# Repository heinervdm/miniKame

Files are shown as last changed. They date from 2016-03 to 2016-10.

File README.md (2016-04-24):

# Kame (MiniKame)

<p align="center">
 
</p>

[¿What do I need for building this robot?](https://github.com/bqlabs/miniKame/wiki/BOM)

[¿Where can I find the assembly model?](https://github.com/bqlabs/miniKame/blob/develop/parts/freecad/miniKame.fcstd)

# License

Son of [Kame](https://github.com/bqlabs/kame)

<p align="center">

</p>

# Remixes
[PoorKame](https://github.com/owenlab/PoorKame) by [owenlab](https://github.com/owenlab)

[FatKame](https://github.com/Blomdoft/fatKame) by [Blomdoft](https://github.com/Blomdoft)

# Other



Sponsored by BQ till march 2016

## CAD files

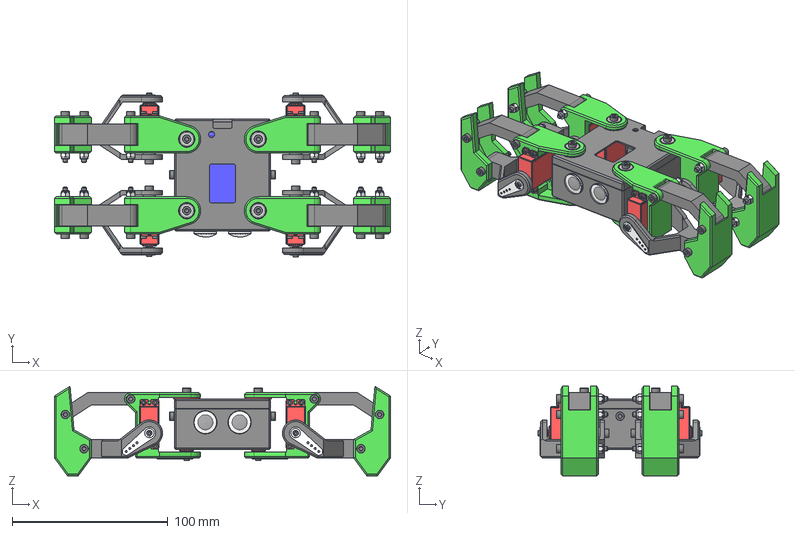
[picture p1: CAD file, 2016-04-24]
parts/freecad/miniKame.fcstd
216.0 x 105.3 x 57.6 mm
Clone of TGY-306G003
Clone of TGY-306G
Clone of TGY-306G004
Clone of TGY-306G005
Clone of TGY-306G006
Clone of TGY-306G007
Clone of TGY-306G008
Clone of TGY-306G009
Clone of horn001 (Mirror #9)
Clone of horn002 (Mirror #10)
Clone of horn001 (Mirror #11)
Clone of horn002 (Mirror #12)
Clone of legA (Mirror #17)
Clone of foot (Mirror #18)
Clone of bracket (Mirror #20)
Clone of legA (Mirror #21)
Clone of foot (Mirror #22)
Clone of bracket (Mirror #24)
Clone of legB (Mirror #30)
Clone of legB (Mirror #31)
Clone of spacer (Mirror #39)
Clone of spacer (Mirror #40)
Clone of bodyB
Clone of bodyA
eye-base
black-eye
eye-cover
eye-base001
eye-cover001
black-eye001
Clone of bearing
Clone of bearing002
Clone of bearing003
Clone of bearing004
Clone of bearing001
Clone of bearing005
Clone of bearing006
Clone of bearing007
Clone of hex-m3-8mm
Clone of hex-m3-8mm001
Clone of hex-m3-8mm002
Clone of hex-m3-8mm003
Clone of hex-m3-8mm004
Clone of hex-m3-8mm005
Clone of hex-m3-8mm006
Clone of hex-m3-8mm007
Clone of hex-m3-8mm008
Clone of hex-m3-8mm009
Clone of hex-m3-30mm
Clone of hex-m3-30mm001
Clone of hex-m3-30mm002
Clone of hex-m3-30mm003
Clone of hex-m3-30mm004
Clone of hex-m3-30mm005
Clone of hex-m3-30mm006
Clone of hex-m3-30mm007
Clone of hex-m3-30mm008
Clone of hex-m3-30mm009
Clone of hex-m3-30mm010
Clone of hex-m3-30mm011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

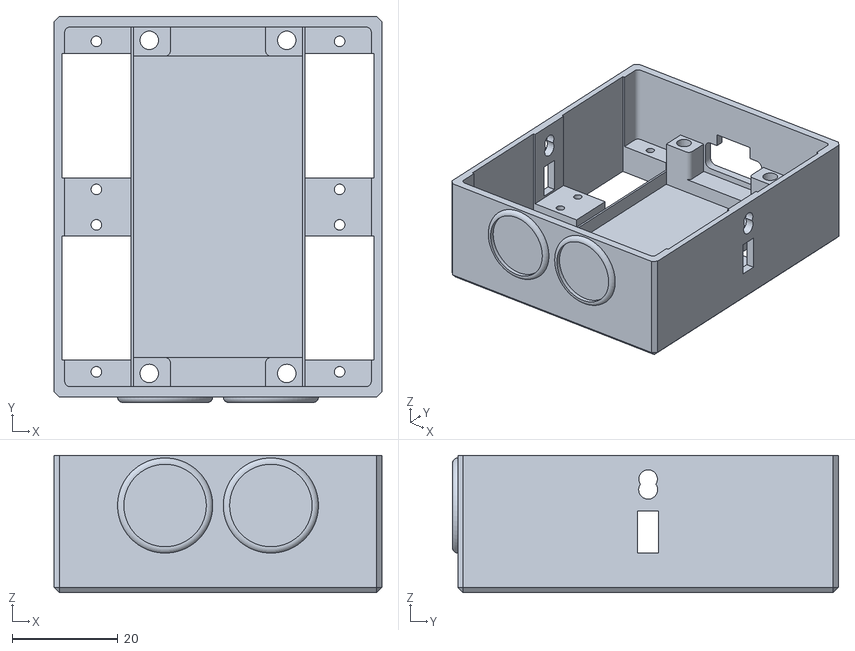
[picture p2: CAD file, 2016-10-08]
parts/stl/BodyA_mod.stl
62.0 x 73.0 x 26.0

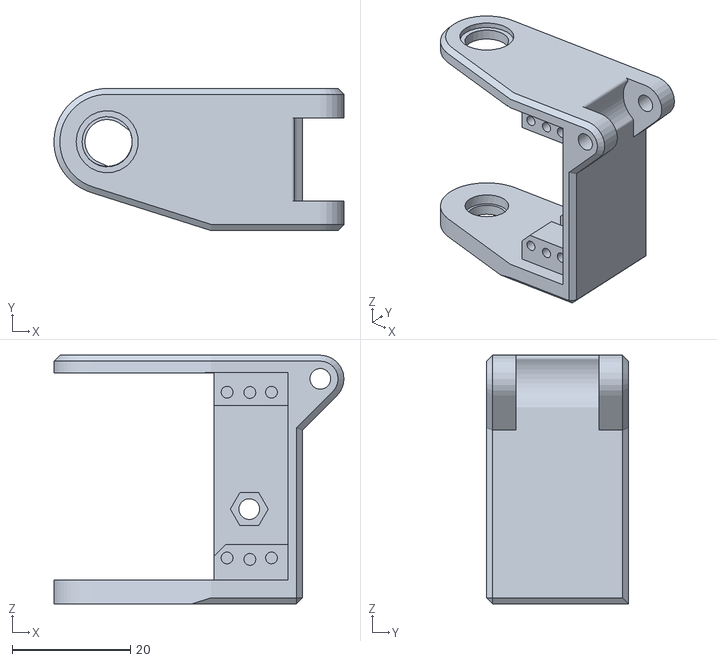
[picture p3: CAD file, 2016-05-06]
parts/stl/leftBracket_mod.stl
49.0 x 24.0 x 42.0

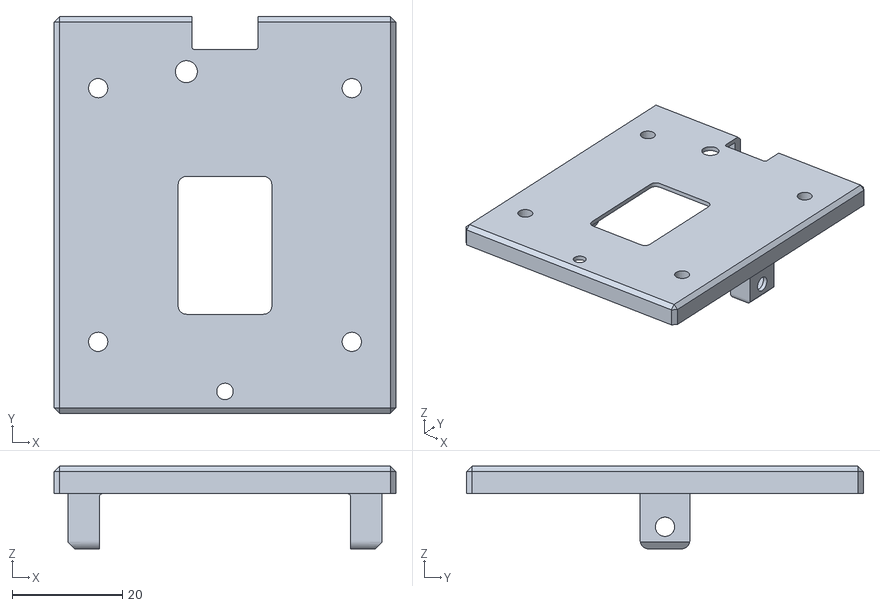
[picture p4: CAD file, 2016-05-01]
parts/stl/BodyB_mod.stl
62.0 x 72.0 x 15.0

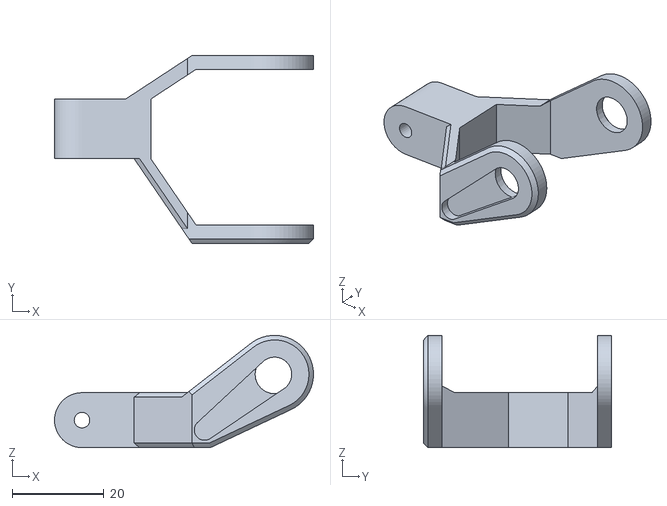
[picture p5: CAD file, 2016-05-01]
parts/stl/rightLegB_mod.stl
56.5 x 41.0 x 24.5

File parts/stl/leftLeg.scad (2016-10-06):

$fn=40;
//union() {
//	import("leftLegB.stl");
//	difference() {
//		color("red") translate([47,-50,7]) rotate([90,38.5,0]) hull() {
//			cylinder(h=2,d=9,center=true);
//			translate([19.25,0,0]) cylinder(h=2,d=5.5,center=true);
//		}
//		translate([47,-50,7]) rotate([90,38.5,0]) hull() {
//			cylinder(h=2,d=7.5,center=true);
//			translate([14,0,0]) cylinder(h=2,d=4.5,center=true);
//		}
//	}
//}
//translate([89,-27.5+1.5,-3]) {
mirror([0,1,0]) {
difference() {
	union() {
		difference() {
			union() {
				rotate([90,0,0]) cylinder(h=13,d=12,center=true);
				translate([-15/2,0,0]) cube([15,13,12],center=true);
			}
			rotate([90,0,0]) cylinder(h=15,d=3.5,center=true);
		}
		translate([0,37,0]) hull() {
			translate([-27,-22-0.5,0]) cube([5,3,12],center=true);
			translate([-42,-22-0.5,18-17/2]) rotate([90,0,0]) cylinder(h=3,d=17,center=true);
		}
		hull() {
			translate([-27,-22-1,0]) cube([5,4,12],center=true);
			translate([-42,-22-1,18-17/2]) rotate([90,0,0]) cylinder(h=4,d=17,center=true);
		}
		hull() {
			translate([-12.5,6.5,0]) cube([5,0.1,12],center=true);
			translate([-24.5,37-22-0.5,0]) cube([0.1,3,12],center=true);
		}
		hull() {
			translate([-13.5,-6.5,0]) cube([3,0.1,12],center=true);
			translate([-24.5,-22-1,0]) cube([0.1,4,12],center=true);
		}
	}
	union() {
		translate([-42,-25,18-17/2]) {
			rotate([90,0,0]) cylinder(h=10,d=8,center=true);
			rotate([90,38.5,0]) hull() {
				cylinder(h=4,d=8,center=true);
				translate([14,0,0]) cylinder(h=4,d=4.5,center=true);
			}
		}
		translate([-42,37-22-0.5,18-17/2]) {
			translate([0,-1,0]) rotate([90,0,0]) cylinder(h=6,d=8.5,center=true);
			translate([0,2,0]) rotate([90,0,0]) cylinder(h=2,d=10.5,center=true);
		}
	}
}
}

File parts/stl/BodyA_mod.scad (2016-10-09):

$fn=50;
import("BodyAmod.stl");
translate([23,0,2.5]) difference() {
	cube([13,11,2], center=true);
	union() {
		translate([0,-3.4,0]) cylinder(h=10,d=2,center=true);
		translate([0,3.3,0]) cylinder(h=10,d=2,center=true);
	}
}
translate([23,32,2.5]) difference() {
	cube([13,6,2], center=true);
	translate([0,-0.7,0]) cylinder(h=10,d=2,center=true);
}
translate([23,-32,2.5]) difference() {
	cube([13,6,2], center=true);
	translate([0,0.8,0]) cylinder(h=10,d=2,center=true);
}
translate([-23,0,2.5]) difference() {
	cube([13,11,2], center=true);
	union() {
		translate([0,-3.4,0]) cylinder(h=10,d=2,center=true);
		translate([0,3.3,0]) cylinder(h=10,d=2,center=true);
	}
}
translate([-23,32,2.5]) difference() {
	cube([13,6,2], center=true);
	translate([0,-0.7,0]) cylinder(h=10,d=2,center=true);
}
translate([-23,-32,2.5]) difference() {
	cube([13,6,2], center=true);
	translate([0,0.8,0]) cylinder(h=10,d=2,center=true);
}

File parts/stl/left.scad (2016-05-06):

$fn=40;
union() {
	difference() {
		import("leftBracket.stl");
		union() {
			translate([39.5,-38.001,-5]) cube([14,3,6.1]);
			translate([39.5,-38.001,24]) cube([14,3,6.1]);
			color("red") translate([47.1,-33.1,26.7]) rotate([90,0,0]) cylinder(h=10,d=2,center=true);
			color("red") translate([47.1,-33.1,-1.5]) rotate([90,0,0]) cylinder(h=10,d=2,center=true);
		}
	}
	difference() {
		translate([23,-23,-8]) rotate([0,0,-30]) hull() {
			cylinder(h=2,d=10,center=true);
			translate([20,0,0]) cylinder(h=2,d=6,center=true);
		}
		translate([23,-23,-8]) rotate([0,0,-30]) hull() {
			cylinder(h=2,d=7.5,center=true);
			translate([14,0,0]) cylinder(h=2,d=4.5,center=true);
		}
	}
}

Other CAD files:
parts/stl/rightBracket_mod.stl
parts/stl/leftLegB_mod.stl
parts/stl/rightLeg.scad
parts/stl/BodyAmod.stl
parts/stl/BodyBmod.stl
parts/stl/right.scad

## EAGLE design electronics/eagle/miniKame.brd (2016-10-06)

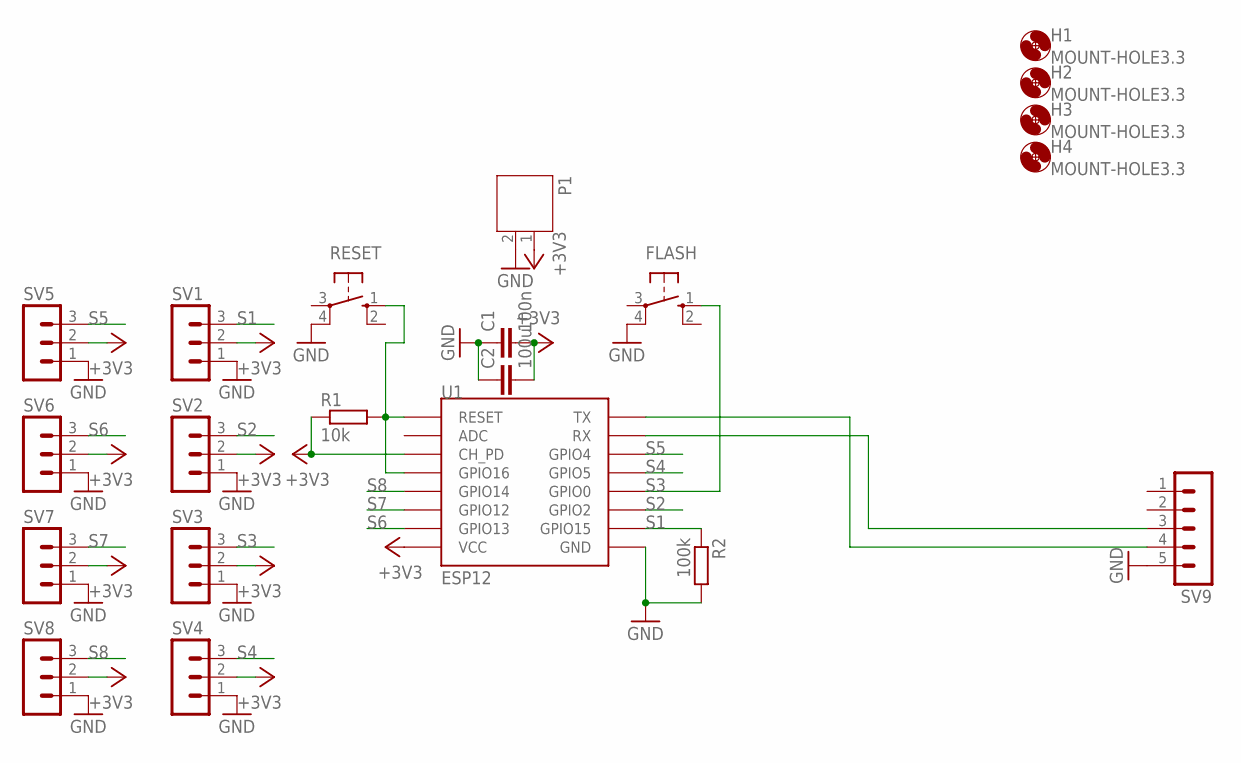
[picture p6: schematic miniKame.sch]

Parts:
C1: 100n; C0805
C2: 100u; C0805
FLASH: 10-XX; B3F-10XX
H1, H2, H3, H4: MOUNT-HOLE3.3; 3,3
P1: JST-PH2
R1: 10k; M0805
R2: 100k; M0805
RESET: 10-XX; B3F-10XX
SV1, SV2, SV3, SV4, SV5, SV6, SV7, SV8: MA03-1
SV9: MA05-1
U1: ESP12

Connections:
+3V3: C1.2, C2.2, P1.1, R1.1, SV1.2, SV2.2, SV3.2, SV4.2, SV5.2, SV6.2, SV7.2, SV8.2, U1.CH_PD, U1.VCC
GND: C1.1, C2.1, FLASH.4 (P1), P1.2, R2.2, RESET.4 (P1), SV1.1, SV2.1, SV3.1, SV4.1, SV5.1, SV6.1, SV7.1, SV8.1, SV9.5, U1.GND
unnamed: SV9.4, U1.TX
unnamed: SV9.3, U1.RX
unnamed: R1.2, RESET.1 (S), U1.GPIO16, U1.RESET
S1: R2.1, SV1.3, U1.GPIO15
S2: SV2.3, U1.GPIO2
S3: FLASH.1 (S), SV3.3, U1.GPIO0
S4: SV4.3, U1.GPIO5
S5: SV5.3, U1.GPIO4
S6: SV6.3, U1.GPIO13
S7: SV7.3, U1.GPIO12
S8: SV8.3, U1.GPIO14

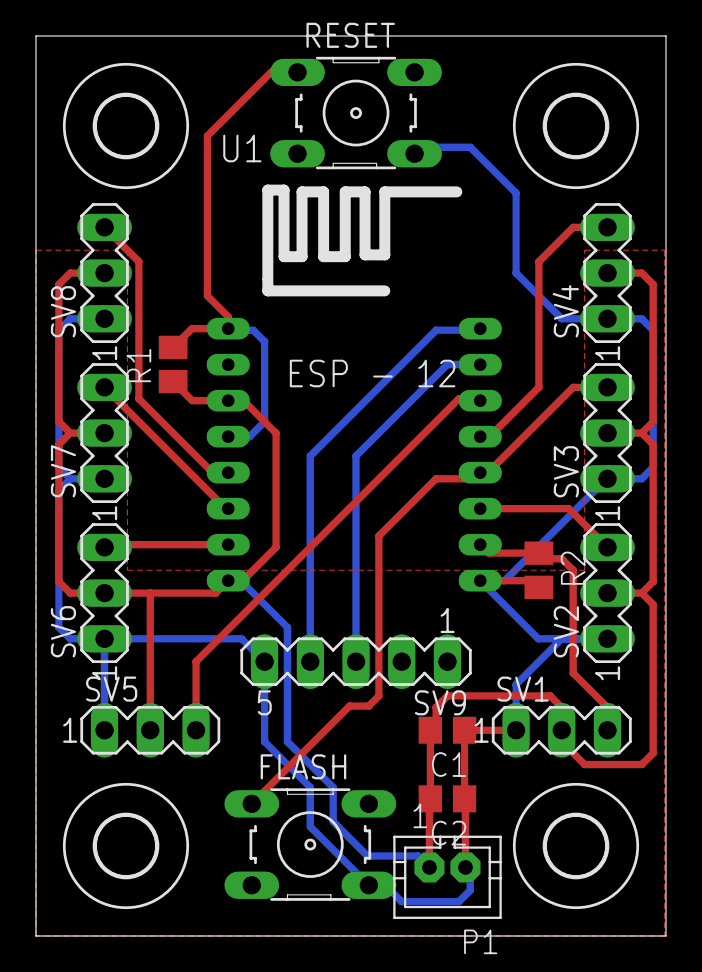
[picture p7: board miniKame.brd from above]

Board: 2 copper layers, 35.0 x 50.0 mm, 21 parts (0 on the bottom side), 13 nets.

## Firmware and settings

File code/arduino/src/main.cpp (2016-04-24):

#include <Arduino.h>
#include <ESP8266WiFi.h>
#include <WiFiClient.h>
#include <Servo.h>
#include "octosnake.h"
#include "minikame.h"

const char* ssid = "kame";
const char* password = "asdf";

MiniKame robot;
WiFiServer server(80);
bool running=0;

void setup() {
    WiFi.mode(WIFI_AP);
    WiFi.softAP(ssid, password);
    server.begin();
    Serial.begin(115200);

    delay(1000);
    robot.init();
}

void parseData(String data){

    //switch (data.substring(0,plusIndex).toInt()){
    switch (data.toInt()){

        case 1:
            robot.walk(1,550);
            running = 1;
            break;

        case 2:

            break;

        case 3:
            robot.turnL(1,550);
            running = 1;
            break;

        case 4:
            robot.turnR(1,550);
            running = 1;
            break;

        case 5:
            //STOP
            running = 0;
            break;

        case 6: //heart
            robot.pushUp(2,1400);
            break;

        case 7: //fire
            robot.upDown(4,250);
            break;

        case 8: //skull
            robot.jump();
            break;

        case 9: //cross
            robot.hello();
            break;

        case 10: //punch
        //robot.moonwalkL(4,2000);
        robot.frontBack(4,200);
            break;

        case 11: //mask
            robot.dance(2,1000);
            break;

        default:
            robot.home();
            break;
    }
}

String input;

void loop() {
    WiFiClient client = server.available();
    if (!client) {
        Serial.println(WiFi.localIP());
        delay(1000);
    }
    while (client.connected()) {
        if (running){
            Serial.println("running");
            if (client.available()) {
                while(client.available()) input = client.readStringUntil('+');
                parseData(input);
            }
            else {
                Serial.println("Keep Moving");
                parseData(input);
            }
        }
        else{
            Serial.println("Normal mode");
            if (client.available()) {
                while(client.available()) input = client.readStringUntil('+');
                parseData(input);
            }
            else robot.home();
        }
    }
}

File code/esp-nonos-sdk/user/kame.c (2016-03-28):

#define USE_US_TIMER

#include "ets_sys.h"
#include "osapi.h"
#include "os_type.h"
#include "kame.h"
#include "gpio.h"
#include "espmissingincludes.h"

#define PI 3.1415

#ifndef DEG2RAD
  #define DEG2RAD(g) ((g)*M_PI)/180
#endif

struct oscillator {
	int16_t period;
	int16_t amplitude;
	int16_t phase;
	int16_t offset;
	int16_t trim;
	bool stop;
	uint32_t ref_time;
	uint32_t delta_time;
};

static struct oscillator osc[8];
uint16_t servo[8];
int16_t board_pins[8];
int16_t trim[8];
bool reverse[8];
uint32_t _init_time;
uint32_t _final_time;
uint32_t _partial_time;
float _increment[8];
float _servo_position[8];

static os_timer_t pulse_timer;
static os_timer_t servo_timer[8];

// https://stackoverflow.com/questions/18805627/decode-an-aproximation-of-sin-taylor-series
float sine(float x) {
    float val = 1;
	int j = 6;
    for (int k = j - 1; k >= 0; --k)
        val = 1 - x*x/(2*k+2)/(2*k+3)*val;

    return x * val;
}

float ICACHE_FLASH_ATTR time_to_radians(struct oscillator osc, double time) {
    return time*2*PI/osc.period;
}

float ICACHE_FLASH_ATTR degrees_to_radians(float degrees){
    return degrees*2*PI/360.;
}

float ICACHE_FLASH_ATTR degrees_to_time(struct oscillator osc, float degrees) {
    return degrees*osc.period/360.;
}

float ICACHE_FLASH_ATTR oscillator_refresh(struct oscillator osc) {
    osc.delta_time = (system_get_time()-osc.ref_time) % osc.period;
    return      (float)osc.amplitude*sine(time_to_radians(osc, osc.delta_time)
                + degrees_to_radians(osc.phase))
                + osc.offset
                + osc.trim;
}

void ICACHE_FLASH_ATTR oscillator_reset(struct oscillator osc) {
	osc.ref_time = system_get_time();
}

void ICACHE_FLASH_ATTR oscillator_init(struct oscillator osc) {
	osc.period = 2000;
    osc.amplitude = 50;
    osc.phase = 0;
    osc.offset = 0;
    osc.stop = false;
    osc.ref_time = system_get_time();
    osc.delta_time = 0;
    osc.trim = 0;
}

int16_t ICACHE_FLASH_ATTR angToUsec(float value){
    return value/180 * (MAX_PULSE_WIDTH-MIN_PULSE_WIDTH) + MIN_PULSE_WIDTH;
}

static void ICACHE_FLASH_ATTR servo0_timerfunc(void *arg) {
	GPIO_OUTPUT_SET(board_pins[0],0);
}

static void ICACHE_FLASH_ATTR servo1_timerfunc(void *arg) {
	GPIO_OUTPUT_SET(board_pins[1],0);
}

static void ICACHE_FLASH_ATTR servo2_timerfunc(void *arg) {
	GPIO_OUTPUT_SET(board_pins[2],0);
}

static void ICACHE_FLASH_ATTR servo3_timerfunc(void *arg) {
	GPIO_OUTPUT_SET(board_pins[3],0);
}

static void ICACHE_FLASH_ATTR servo4_timerfunc(void *arg) {
	GPIO_OUTPUT_SET(board_pins[4],0);
}

static void ICACHE_FLASH_ATTR servo5_timerfunc(void *arg) {
	GPIO_OUTPUT_SET(board_pins[5],0);
}

static void ICACHE_FLASH_ATTR servo6_timerfunc(void *arg) {
	GPIO_OUTPUT_SET(board_pins[6],0);
}

static void ICACHE_FLASH_ATTR servo7_timerfunc(void *arg) {
	GPIO_OUTPUT_SET(board_pins[7],0);
}

static void ICACHE_FLASH_ATTR pulse_timerfunc(void *arg) {
	os_timer_func_t *timerfuncarr[8] = {
		(os_timer_func_t *)servo0_timerfunc,
		(os_timer_func_t *)servo1_timerfunc,
		(os_timer_func_t *)servo2_timerfunc,
		(os_timer_func_t *)servo3_timerfunc,
		(os_timer_func_t *)servo4_timerfunc,
		(os_timer_func_t *)servo5_timerfunc,
		(os_timer_func_t *)servo6_timerfunc,
		(os_timer_func_t *)servo7_timerfunc
	};

	for (uint8_t i=0;i<8;i++) {
		GPIO_OUTPUT_SET(board_pins[i],1);
		os_timer_disarm(&servo_timer[i]);
		os_timer_setfn(&servo_timer[i], timerfuncarr[i], NULL);
		os_timer_arm_us(&servo_timer[i], servo[i], 0);
	}
}

void ICACHE_FLASH_ATTR kame_init(){
    board_pins[0] = 1;
    board_pins[1] = 4,
    board_pins[2] = 8;
    board_pins[3] = 6;
    board_pins[4] = 7;
    board_pins[5] = 5;
    board_pins[6] = 2;
    board_pins[7] = 3;

	os_timer_disarm(&pulse_timer);
	os_timer_setfn(&pulse_timer, (os_timer_func_t *)pulse_timerfunc, NULL);
	os_timer_arm(&pulse_timer, 20, 1);

    trim[0] = 1;
    trim[1] = -8;
    trim[2] = 6;
    trim[3] = 4;
    trim[4] = 2;
    trim[5] = -5;
    trim[6] = 6;
    trim[7] = 2;
    for (uint8_t i=0; i<8; i++) reverse[i] = 0;


    for(uint8_t i=0; i<8; i++) osc[i].trim = trim[i];
//     for(uint8_t i=0; i<8; i++) servo[i].attach(board_pins[i]);
    kame_home();
}

void ICACHE_FLASH_ATTR kame_turnR(float steps, float T){
    int16_t x_amp = 15;
    int16_t z_amp = 15;
    int16_t ap = 15;
    int16_t hi = 23;
    float period[] = {T, T, T, T, T, T, T, T};
    int16_t amplitude[] = {x_amp,x_amp,z_amp,z_amp,x_amp,x_amp,z_amp,z_amp};
    int16_t offset[] = {90+ap,90-ap,90-hi,90+hi,90-ap,90+ap,90+hi,90-hi};
    int16_t phase[] = {0,180,90,90,180,0,90,90};

    kame_execute(steps, period, amplitude, offset, phase);
}

void ICACHE_FLASH_ATTR kame_turnL(float steps, float T){
    int16_t x_amp = 15;
    int16_t z_amp = 15;
    int16_t ap = 15;
    int16_t hi = 23;
    float period[] = {T, T, T, T, T, T, T, T};
    int16_t amplitude[] = {x_amp,x_amp,z_amp,z_amp,x_amp,x_amp,z_amp,z_amp};
    int16_t offset[] = {90+ap,90-ap,90-hi,90+hi,90-ap,90+ap,90+hi,90-hi};
    int16_t phase[] = {180,0,90,90,0,180,90,90};

    kame_execute(steps, period, amplitude, offset, phase);
}

void ICACHE_FLASH_ATTR kame_dance(float steps, float T){
    int16_t x_amp = 0;
    int16_t z_amp = 40;
    int16_t ap = 30;
    int16_t hi = 20;
    float period[] = {T, T, T, T, T, T, T, T};
    int16_t amplitude[] = {x_amp,x_amp,z_amp,z_amp,x_amp,x_amp,z_amp,z_amp};
    int16_t offset[] = {90+ap,90-ap,90-hi,90+hi,90-ap,90+ap,90+hi,90-hi};
    int16_t phase[] = {0,0,0,270,0,0,90,180};

    kame_execute(steps, period, amplitude, offset, phase);
}

void ICACHE_FLASH_ATTR kame_run(float steps, float T){
    int16_t x_amp = 15;
    int16_t z_amp = 15;
    int16_t ap = 15;
    int16_t hi = 15;
    int16_t front_x = 6;
    float period[] = {T, T, T, T, T, T, T, T};
    int16_t amplitude[] = {x_amp,x_amp,z_amp,z_amp,x_amp,x_amp,z_amp,z_amp};
    int16_t offset[] = {    90+ap-front_x,
                        90-ap+front_x,
                        90-hi,
                        90+hi,
                        90-ap-front_x,
                        90+ap+front_x,
                        90+hi,
                        90-hi
                    };
    int16_t phase[] = {0,0,90,90,180,180,90,90};

    kame_execute(steps, period, amplitude, offset, phase);
}

void ICACHE_FLASH_ATTR kame_moonwalkL(float steps, float T){
    int16_t z_amp = 45;
    float period[] = {T, T, T, T, T, T, T, T};
    int16_t amplitude[] = {0,0,z_amp,z_amp,0,0,z_amp,z_amp};
    int16_t offset[] = {90, 90, 90, 90, 90, 90, 90, 90};
    int16_t phase[] = {0,0,0,120,0,0,180,290};

    kame_execute(steps, period, amplitude, offset, phase);
}
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

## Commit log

2016-04-24 Add modified brackets
    [left.scad, leftBracket_mod.stl, right.scad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]
2016-04-24 Add modified body from https://github.com/owenlab/poorkame
    [BodyAmod.stl, BodyBmod.stl]
2016-04-24 Make brackets fit better
    [left.scad, leftBracket_mod.stl, right.scad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]
2016-04-25 Add initial version of a PCB, not yet finished
    [miniKame.brd, miniKame.sch]
2016-04-25 update PCB
2016-05-01 modify leg parts to better fit SG90 servo horns
    [left.scad, leftBracket_mod.stl, leftLeg.scad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]
2016-05-01 Add bodyB with larger screwholes, my printer prints them to small
    [BodyB_mod.scad, BodyB_mod.stl]
2016-05-06 update servohorn size of brackets
    [left.scad, leftBracket_mod.stl, right.scad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]
2016-10-06 Rebuild leftLegB completly in openSCAD
    [leftLeg.scad]
2016-10-08 Add modfied Body which should fit tower pro sg90 servos
    [BodyA_mod.scad]
2016-10-08 Also add stl
    [BodyA_mod.stl]
2016-10-09 Fix BodyA
    [BodyA_mod.scad]

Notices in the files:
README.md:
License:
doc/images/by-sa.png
